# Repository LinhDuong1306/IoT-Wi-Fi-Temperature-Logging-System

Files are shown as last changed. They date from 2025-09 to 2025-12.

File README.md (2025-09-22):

# IoT Wi-Fi Temperature & Humidity Logging System with Alarm
This system records temperature data using a Atmega 328P microcontroller (MCU), Wi-Fi connectivity, and the ThingSpeak application programming interface (API). ThingSpeak is an open-source Internet of Things (IoT) platform that allows devices to send and retrieve data over the Internet.

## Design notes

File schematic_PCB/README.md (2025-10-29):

Thư mục này chứa các file về schematic và PCB

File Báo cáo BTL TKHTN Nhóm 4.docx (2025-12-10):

ĐẠI HỌC QUỐC GIA TP HỒ CHÍ MINH

TRƯỜNG ĐẠI HỌC BÁCH KHOA

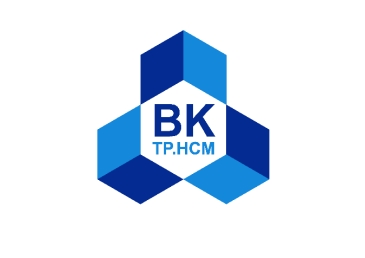
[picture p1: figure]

BÁO CÁO BÀI TẬP LỚN

ĐỀ TÀI

IoT-Wi-Fi Temperature & Humidity Logging System with Alarm

Môn: Thiết kế Hệ thống nhúng

GVHD: Ths BÙI QUỐC BẢO

Họ và tên | MSSV | Nhiệm vụ | Tỉ lệ
Dương Thị Khánh Linh | 2211841 | Thiết kế Hardwave | 100%
Nguyễn Hữu Vinh | 2213970 | Code | 100%

# I. Tổng quan

Trong bối cảnh các hệ thống tự động hóa và công nghệ Internet of Things (IoT) ngày càng phát triển, việc giám sát và đánh giá các thông số môi trường trở nên cần thiết đối với nhiều lĩnh vực khác nhau. Nhiệt độ và độ ẩm là hai yếu tố quan trọng ảnh hưởng trực tiếp đến chất lượng sản phẩm, điều kiện bảo quản, sự ổn định của thiết bị cũng như sức khỏe của con người. Vì vậy, một hệ thống giám sát nhiệt độ và độ ẩm hoạt động liên tục, chính xác và có khả năng cảnh báo kịp thời là yêu cầu cấp thiết trong nhiều ứng dụng thực tiễn.

Hệ thống IoT–Wi-Fi Temperature & Humidity Logging System with Alarm được xây dựng nhằm đáp ứng nhu cầu nói trên. Hệ thống cho phép đo lường và ghi nhận (logging) các giá trị nhiệt độ và độ ẩm theo thời gian thực, đồng thời truyền dữ liệu qua kết nối Wi-Fi lên nền tảng lưu trữ hoặc dashboard trực quan. Thông qua cơ chế cảnh báo tự động, hệ thống sẽ phát hiện và thông báo ngay lập tức khi thông số môi trường vượt ra khỏi giới hạn cho phép, giúp người vận hành kịp thời đưa ra biện pháp xử lý.

Hệ thống phù hợp cho:

- Kho lạnh, phòng thí nghiệm
- Nông nghiệp thông minh
- Nhà ở, văn phòng, phòng Server
- Nhà kính, chuồng trại chăn nuôi
- Quản lý chuỗi cung ứng thực phẩm

# II. Tổng quan hệ thống

## 1. Requirement

Hệ thống IoT-Wi-Fi Temperature & Humidity Logging System with Alarm được thiết kế nhằm mục đích giám sát và ghi lại dữ liệu nhiệt độ và độ ẩm trong môi trường một cách liên tục và chính xác. Hệ thống không chỉ cung cấp khả năng thu thập dữ liệu từ xa thông qua kết nối Wi-Fi mà còn tích hợp chức năng cảnh báo khi các thông số vượt ngưỡng cho phép, giúp người dùng kịp thời xử lý và duy trì điều kiện môi trường ổn định.

Yêu cầu của hệ thống bao gồm khả năng đo lường chính xác, truyền dữ liệu ổn định, cảnh báo tức thì và giao diện người dùng thân thiện để theo dõi và quản lý dữ liệu hiệu quả. Do đó nhóm đưa ra các yêu cầu hệ thống như sau.

  1.1. Functional Requirement

Number | Description | Note
R1.1 | Đọc được giá trị nhiệt độ & độ ẩm từ cảm biến
R1.2 | Hiển thị dữ liệu đo được lên LCD (Temp xx.x °C, Humi xx.x %RH).
R1.3 | Kết nối Wi-Fi
R1.4 | Gửi dữ liệu (Temp, Humi) lên phần mềm và ứng dụng
R1.5 | Chu kỳ gửi dữ liệu < 30 giây.
R1.6 | Lưu dữ liệu khi mất Wi-Fi.
R1.7 | Tự động đồng bộ dữ liệu khi Wi-Fi phục hồi.
R1.8 | Người dùng có thể xem dữ liệu theo thời gian thực trên trang web hoặc ứng dụng phát triển.
R1.9 | Kích hoạt báo động (buzzer) khi nhiệt độ hoặc độ ẩm vượt ngưỡng.

  1.2. Non-functioanl Requirement

Number | Description | Note
R2.1 | Độ chính xác: Nhiệt độ ±0.5 °C, Độ ẩm ±2 %RH
R2.2 | Ứng dụng hiển thị biểu đồ line chart (Temp & Humi)
R2.3 | Độ trễ từ lúc đo đến khi gửi dữ liệu ≤ 2 giây.
R2.4 | Hoạt động trong môi trường -30 °C đến 80 °C.
R2.5 | Nguồn DC 12V-1A, ổn áp xuống 5V/3.3V.
R2.6 | Sử dụng giao thức HTTP/MQTT chuẩn do phần mềm hiển thị hỗ trợ.
R2.7 | Chi phí linh kiện < 500.000 VND.
R2.8 | Báo động phát trong ≤2 giây kể từ khi vượt ngưỡng.

## 1. Hoạt động hệ thống

Nguyên lý hoạt động của hệ thống gồm ba giai đoạn chính diễn ra tuần hoàn là khởi tạo, xử lý dữ liệu tại chỗ và truyền thông dữ liệu từ xa.

Đầu tiên, ở giai đoạn Khởi tạo, ngay khi được cấp nguồn, khối xử lý trung tâm thực hiện việc cấu hình các chân tín hiệu và kết nối với cảm biến. Đồng thời, module Wi-Fi tích hợp sẽ tiến hành xác thực và kết nối vào mạng Internet cục bộ. Đèn báo trạng thái sẽ phản hồi để xác nhận kết nối mạng thành công, đưa hệ thống vào trạng thái sẵn sàng hoạt động.

Tiếp theo là giai đoạn Thu nhập và Xử lý tại chỗ. Vi điều khiển định kỳ đọc dữ liệu từ cảm biến nhiệt độ và độ ẩm và hiển thị lên LCD. Các giá trị này được so sánh trực tiếp với ngưỡng cảnh báo được thiết lập trong phần mềm (ví dụ: nhiệt độ T > 35ᵒC). Nếu kết quả so sánh cho thấy thông số nằm trong giới hạn an toàn, hệ thống duy trì trạng thái giám sát bình thường. Tuy nhiên, nếu phát hiện thông số vượt ngưỡng, vi điều khiển sẽ kích hoạt khối cảnh báo: còi buzzer sẽ phát âm thanh báo động để cảnh báo người dùng tại hiện trường xử lý kịp thời. Có một nút nhấn cho phép bật tắt cảnh báo, ban đầu là hệ thống cho cho phép cảnh báo hoạt động đồng thời led báo hiệu sáng, sau khi cảnh báo đã bật, khi nhấn nút cảnh báo sẽ tắt đồng thời led báo hiệu cũng tắt.

Cuối cùng là giai đoạn Ghi dữ liệu và Giám sát từ xa (IoT Logging). Bất kể trạng thái là bình thường hay cảnh báo, dữ liệu nhiệt độ và độ ẩm đều được vi điều khiển đóng gói và gửi lên máy chủ đám mây (Cloud Server) thông qua giao thức mạng (như HTTP hoặc MQTT). Nền tảng Cloud (như ThingSpeak, Blynk) sẽ nhận gói tin, lưu trữ dữ liệu theo thời gian thực và cập nhật biểu đồ trên giao diện người dùng. Điều này cho phép người quản lý không chỉ theo dõi tình trạng hiện tại mà còn có thể xem lại lịch sử biến thiên của môi trường theo thời gian. Sau khi hoàn tất gửi dữ liệu, hệ thống chuyển sang chế độ chờ trong một khoảng thời gian định trước khi bắt đầu chu kỳ đo mới.

## 2. Block digram

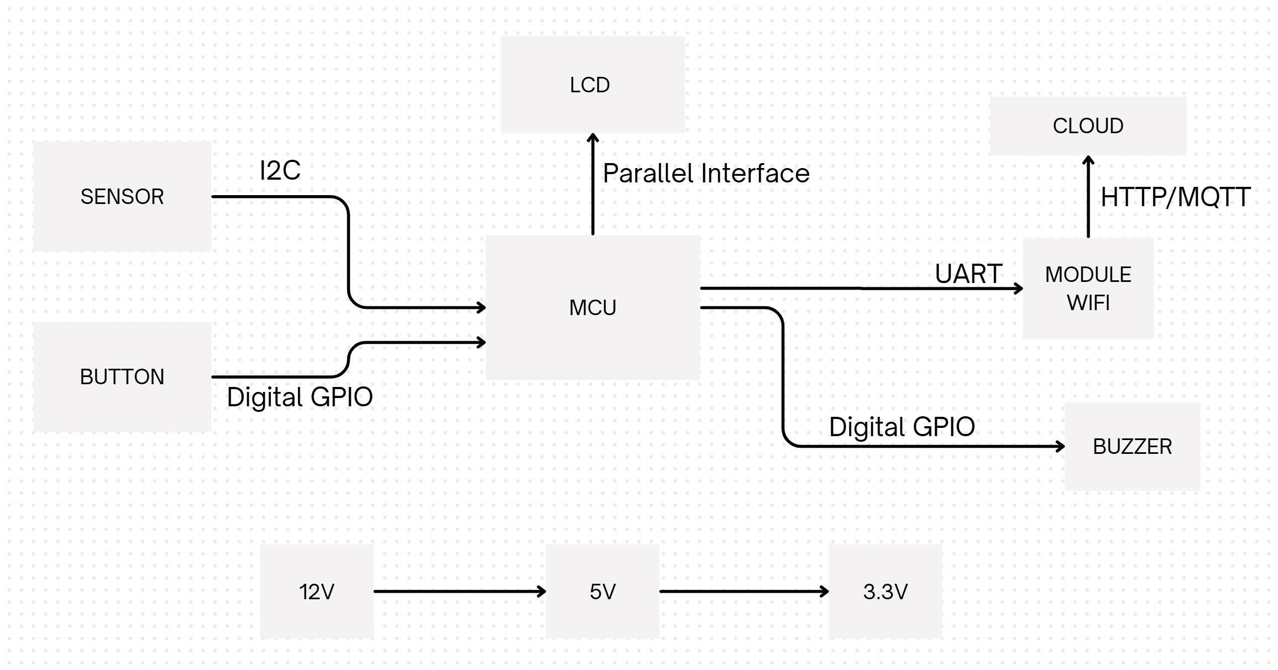
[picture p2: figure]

# III. Thiết kế phần cứng

## 1. Các thành phần, khối

Hệ thống gồm các khối sau:

  1.1. Khối cảm biến

Yêu cầu độ chính xác Nhiệt độ ±0.5 °C, Độ ẩm ±2 %RH, từ đó lựa chọn Sensor nhiệt độ, độ ẩm AHT20 cho thiết kế, IC có nguồn cấp là 5V. Giao tiếp bằng giao thức I2C. Tụ lọc nguồn của IC có công thức tính như sau:

C≥(I_(trsnsient) ×∆t)/(∆V_(ripple))

Chọn tụ có giá trị 1uF

  1.2. Khối module wifi

Yêu cầu có thể gửi dữ liệu lên Internet, có thể kết nối wifi, khoảng cách giữa các các lần gửi ≤ 30s. Có thể truyền dữ liệu bằng giao thức MQTT hoặc HTTP. Từ đó lựa chọn ESP8266 ESP – 01 để thực hiện chức năng này. Giao tiếp bằng giao thức UART.

ESP – 01 có điện áp cấp là 3.3V tương tự cho các IC khác ta cũng có tụ bypass nguồn cho ESP – 01 có giá trị 1uF. Và có nhút nhấn button reset cho module này.

  1.3. Khối hiển thị, cảnh báo

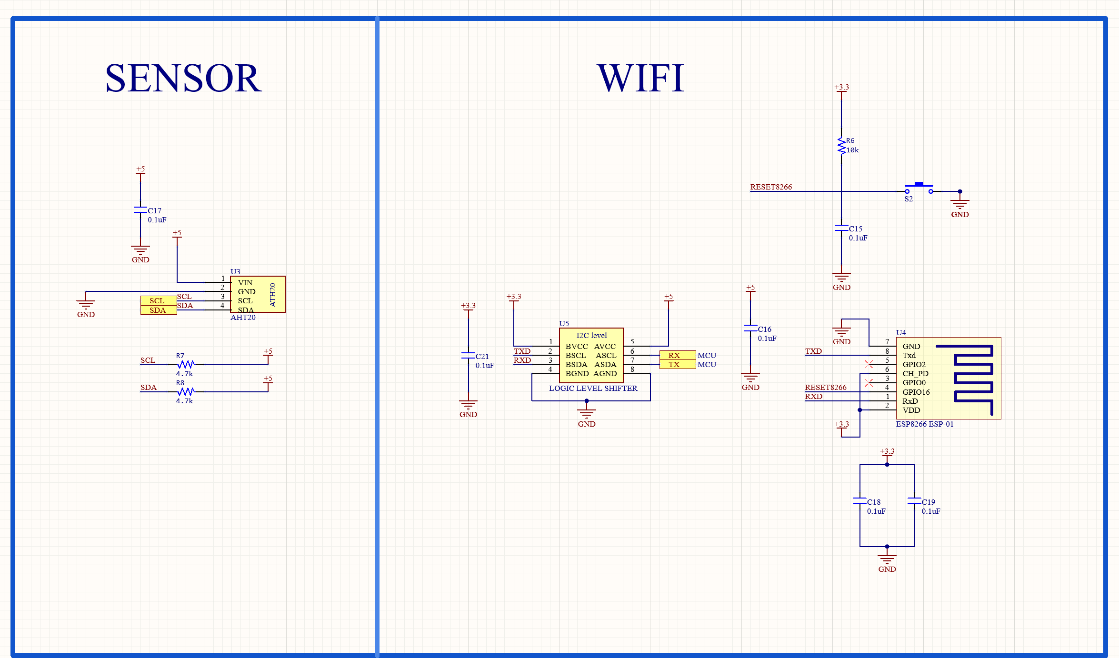
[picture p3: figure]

Hiển thị thông tin cho người dùng: Nhiệt độ, Độ ẩm, Thời gian cho lần gửi dữ liệu tiếp theo. Có Nhận dữ liệu từ MCU và hiển thị text ra màn hình qua giao tiếp. Sử dụng LCD1602 cho mạch, hiển thị.

Còi báo để cảnh báo khi vượt ngưỡng nhiệt độ hoặc độ ẩm. Nhận tín hiệu digital từ MCU, phát âm thanh qua buzzer và phải dùng transistor NPN để khuếch đại dòng, hay để lái Buzzer. Lựa chọn còi passive 5V, Transitor NPN để thực hiện mạch còi.

Thiết kế một nút nhấn button_alarm cho hệ thống với hệ thống.

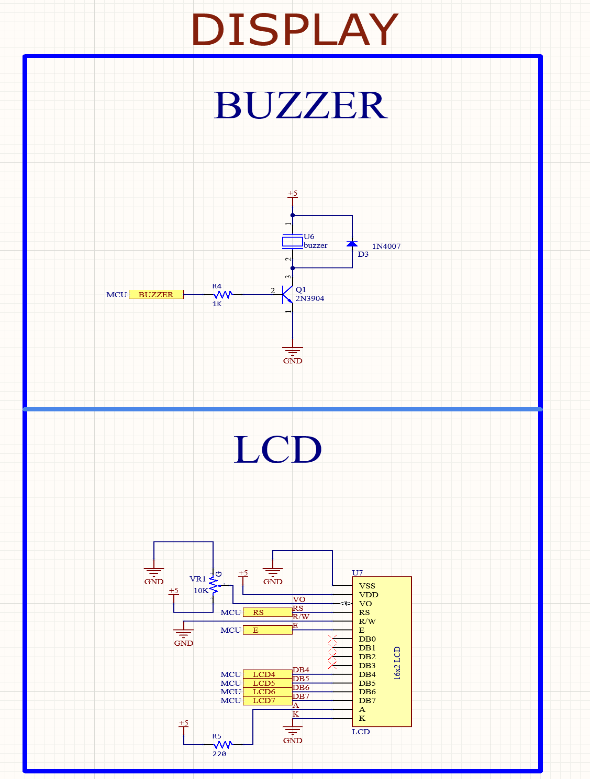
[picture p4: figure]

  1.4. Khối MCU

Hệ thống sử dụng cảm biến AHT20, module WiFi ESP8266, LCD 1602, nút nhấn và còi báo, nên cần một bộ điều khiển có khả năng hỗ trợ đồng thời nhiều chuẩn giao tiếp như I2C để đọc dữ liệu cảm biến, UART để truyền dữ liệu với module WiFi, và các chân GPIO để điều khiển còi, đọc tín hiệu từ nút nhấn cũng như giao tiếp song song với LCD. MCU có đủ số chân I/O để kết nối toàn bộ các thiết bị này mà không cần thêm IC mở rộng. MCU cần có 6 chân điều khiển LCD, 2 chân I2C, 2 chân UART, 2 chân GPIO cho button và buzzer và 4 chân cho mạch nạp code. Tổng 16 I/O, do đó lựa chọn ATmega 328P có 28 chân, trong đó có 20 chân I/O, thư viện phong phú giá thành rẻ làm là vi điều khiển cho toàn hệ thống.

Thiết kế một button_reset cho MCU, tương tự ta chọn các giá trị tụ bypass nguồn để lọc nhiễu đầu vào cho MCU sử dụng công thức trên ta dùng 2 tụ có giá trị 1uF.

Chọn thạch anh ngoài 16MHZ để tạo xung cho mạch. Các tụ đầu vào của thạch anh có giá trị được tính theo công thức:

C_L =(C_1 C_2)/(C_1 +C_2)+C_(stray)

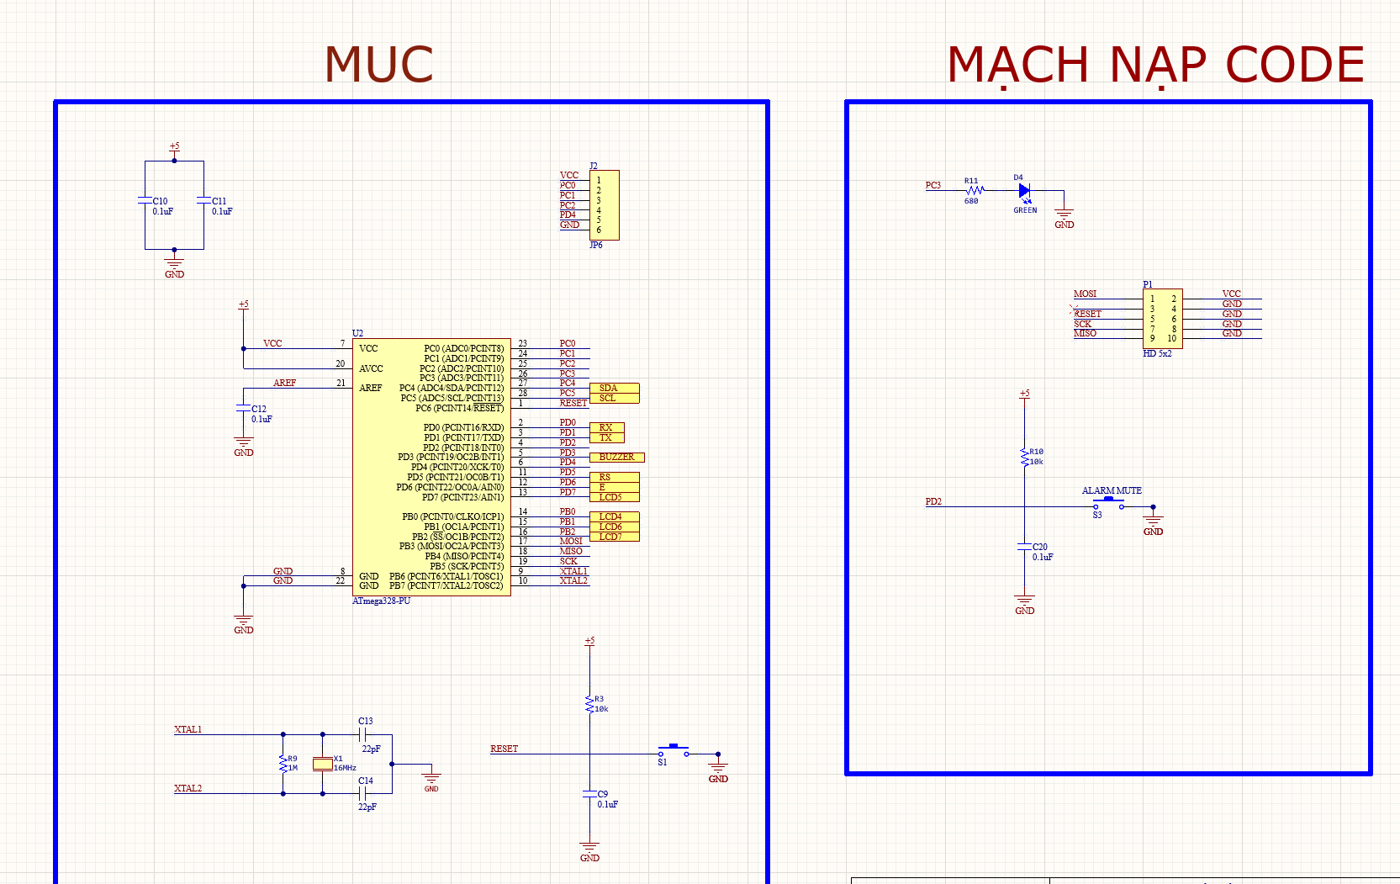
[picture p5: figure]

Chọn C_1 =C_2 , suy ra C có giá trị là 22pF.

  1.5. Khối nguồn

Lựa chọn nguồn Adapter 12V/1A cấp nguồn vào sau đó chuyển đổi xuống 5V để cấp cho MCU, buzzer, LCD và cảm biến. Do đó cần một IC chuyển nguồn, nhóm lựa chọn IC LM7805 để thực hiện tác vụ này. Sử dụng công thức:

C≥(I_(trsnsient) ×∆t)/(∆V_(ripple))

V_(rating) ≥2V_(use)

Chọn tụ 47uF/35V làm chức năng lọc nhiễu và ripple từ adapter đồng thời ổn định đầu vào trước khi vào ổn áp LM7805. Gắn tản nhiệt cho LM7805 ta có:

P_d =(V_(in) -V_(out) )I_(out)

I_(max) =(T_(jmax) -T_a)/((V_(in) -V_(out) )θ_(ja))=700mA

Thêm 1 tụ 22uF/16V đầu vào để lọc ripple từ nguồn cung cấp.

Z_c =1/(2πfC)

Từ đó chọn một tụ ceramic 0.1uF cho HF ở ngõ ra để tần số nhiễu nhỏ. Và một tụ electrolytic 10uF/16V song song với tụ ceramic để ổn định điện áp ngõ ra. Mắc một R và LED để kiểm tra bộ ổn áp hoạt động. Chọn R = 1k, dòng chạy qua nhỏ đủ làm LED sáng và không gây hao hụt gây nóng cho 7805.

I=(5-2)/R=3mA

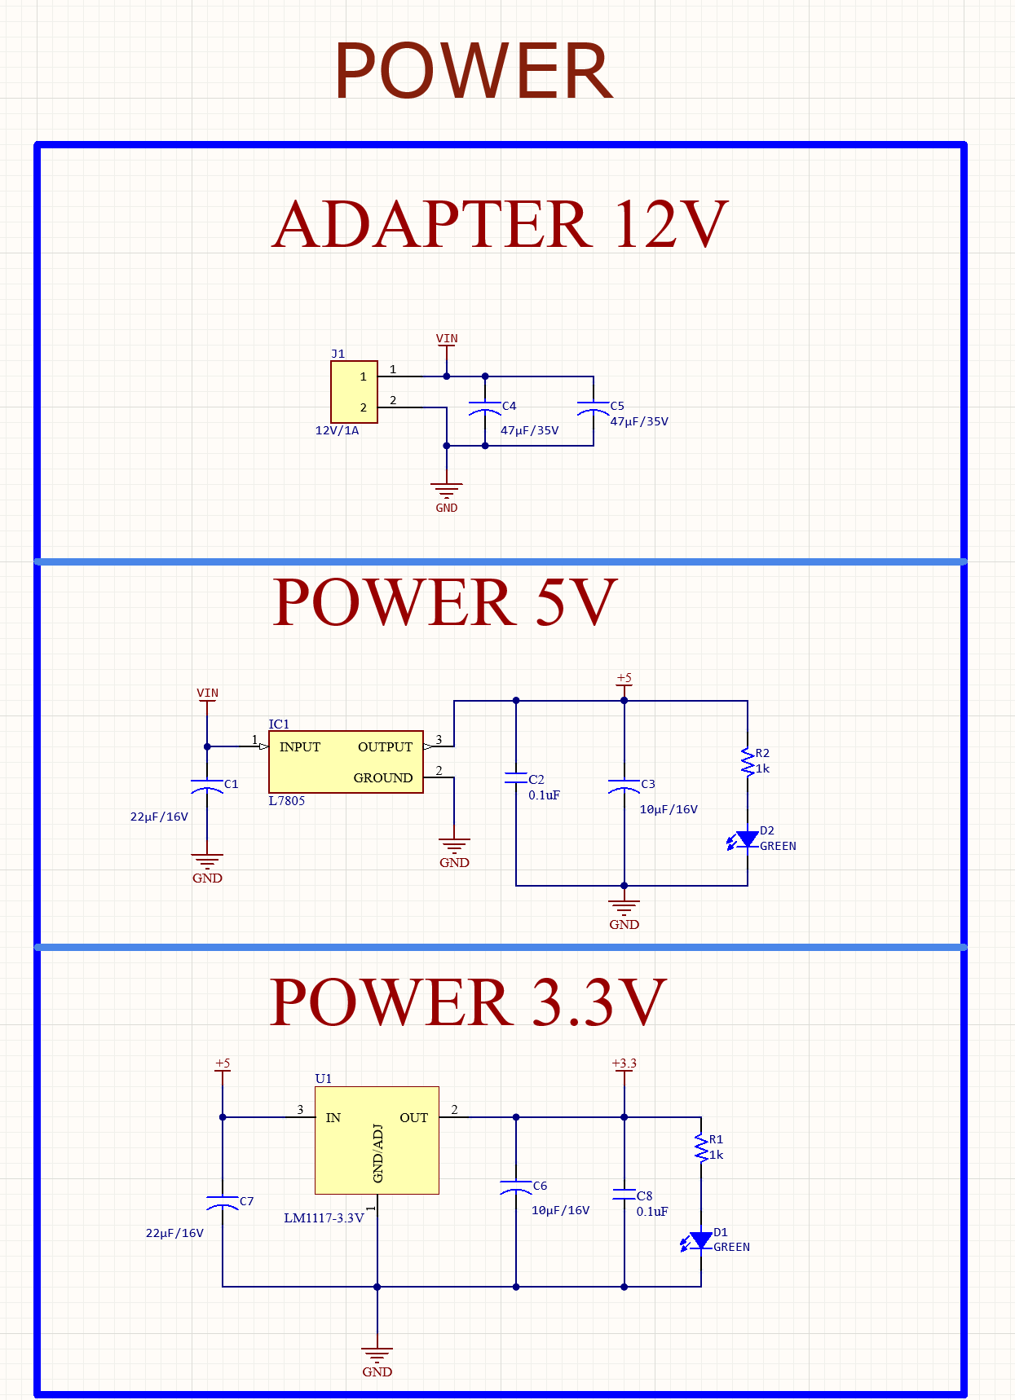
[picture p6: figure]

Bộ chuyển đổi từ 5V về 3.3V để cấp nguồn cho ESP8266 hay ESP-01 tương tự cấu trúc trên.

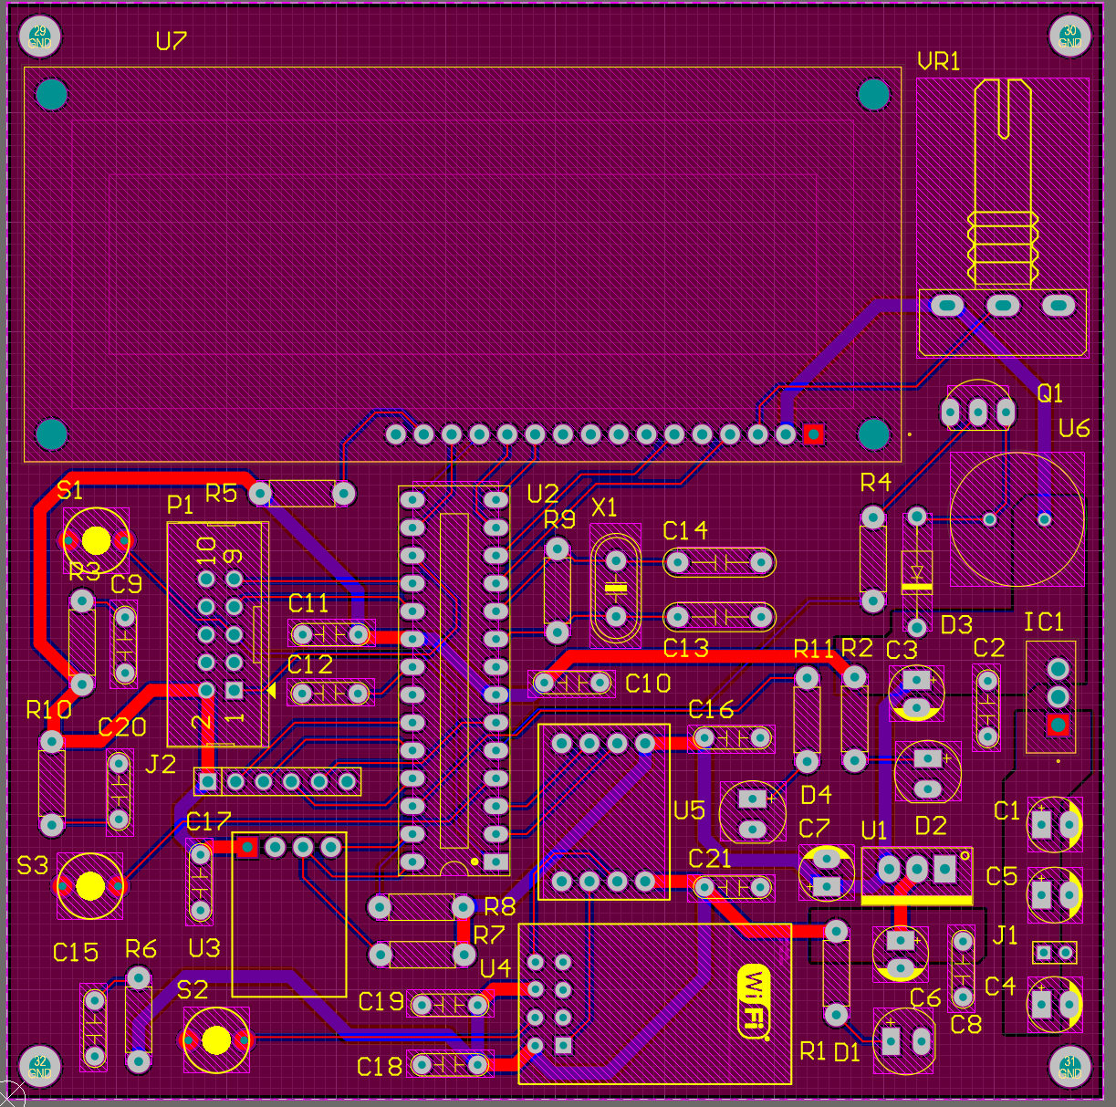
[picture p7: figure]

## 1. Layout PCB

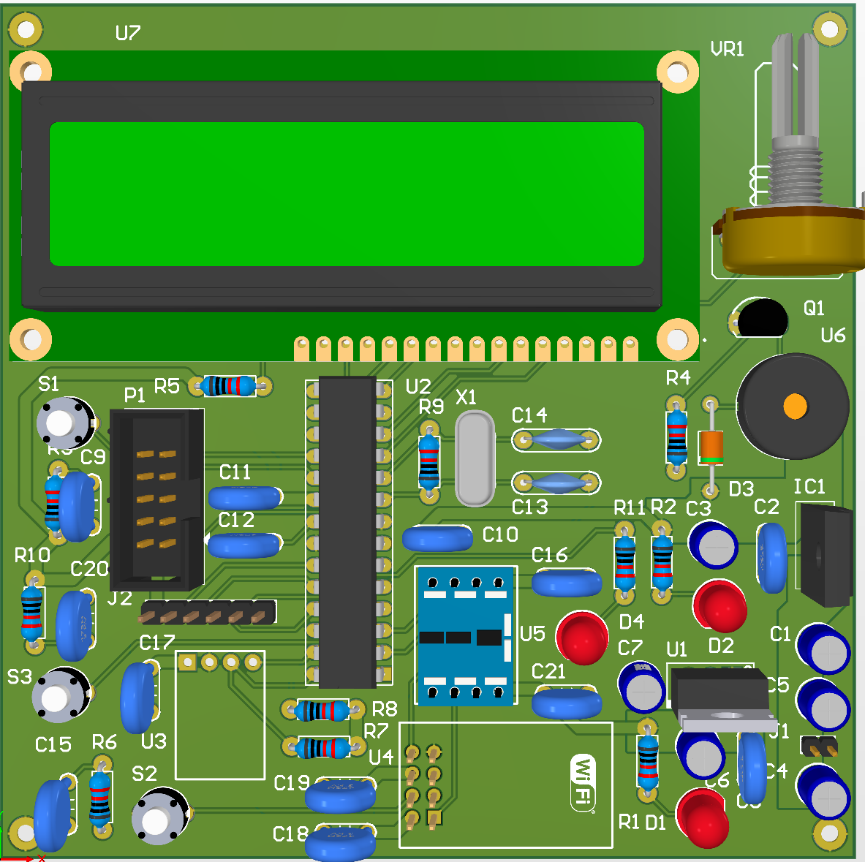
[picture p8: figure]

Mô hình 3D

# IV. Thiết kế phần mềm

## 1. Flow chart button

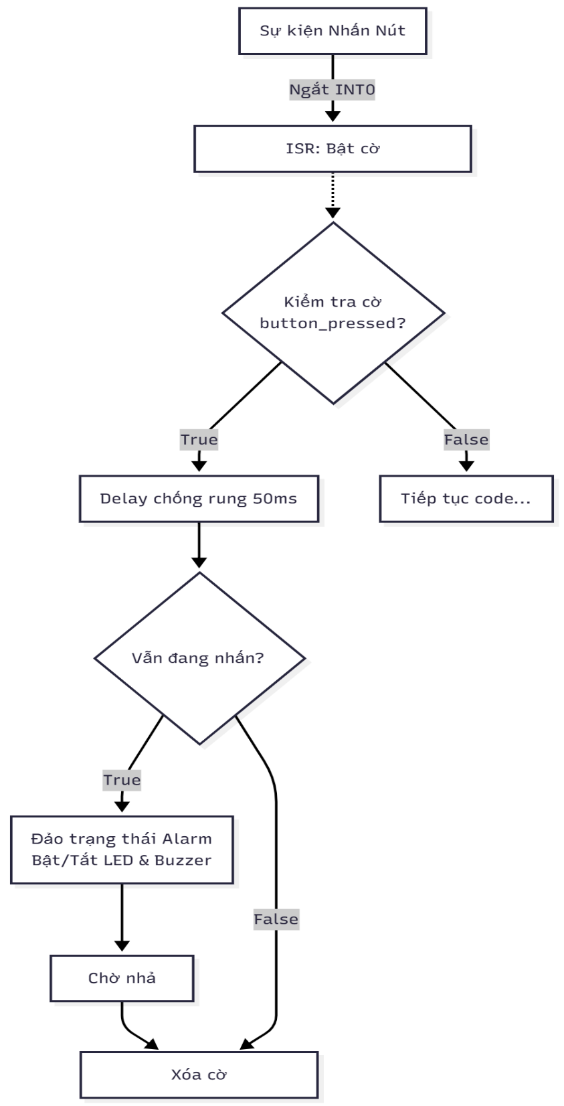
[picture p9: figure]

## 2. Flow chart hệ thống

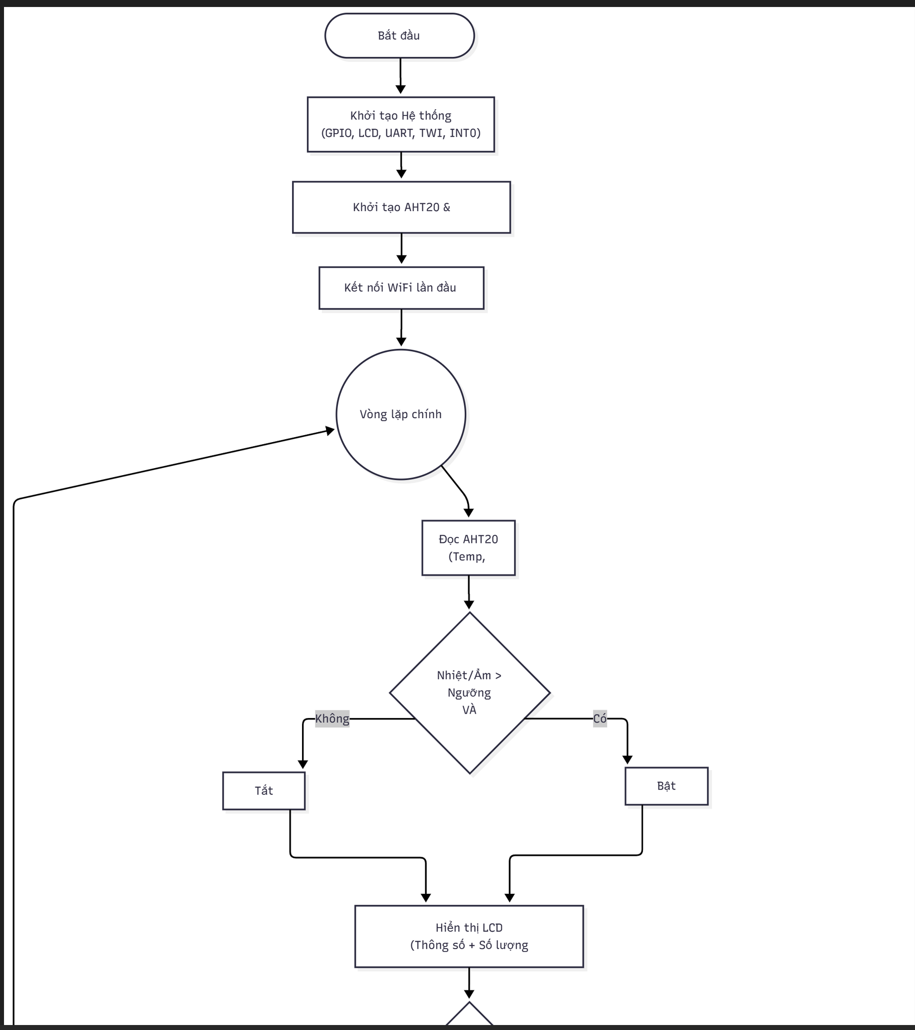
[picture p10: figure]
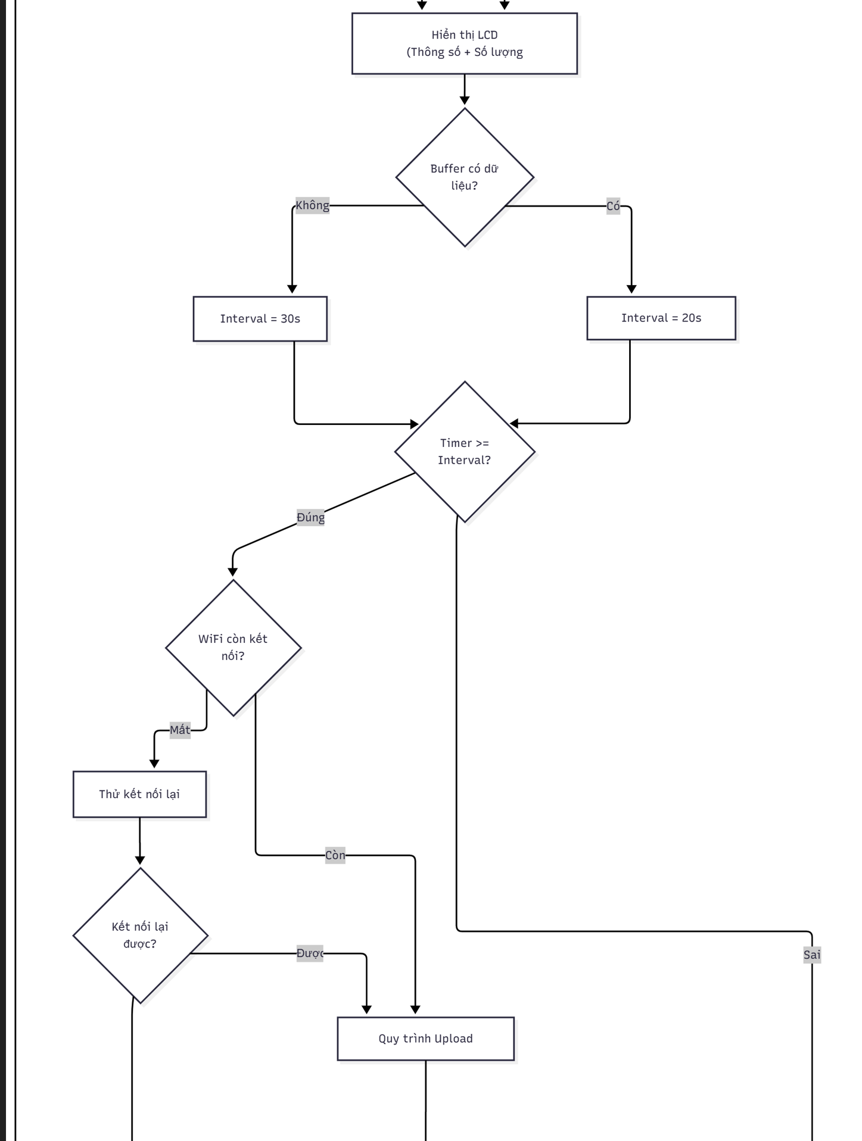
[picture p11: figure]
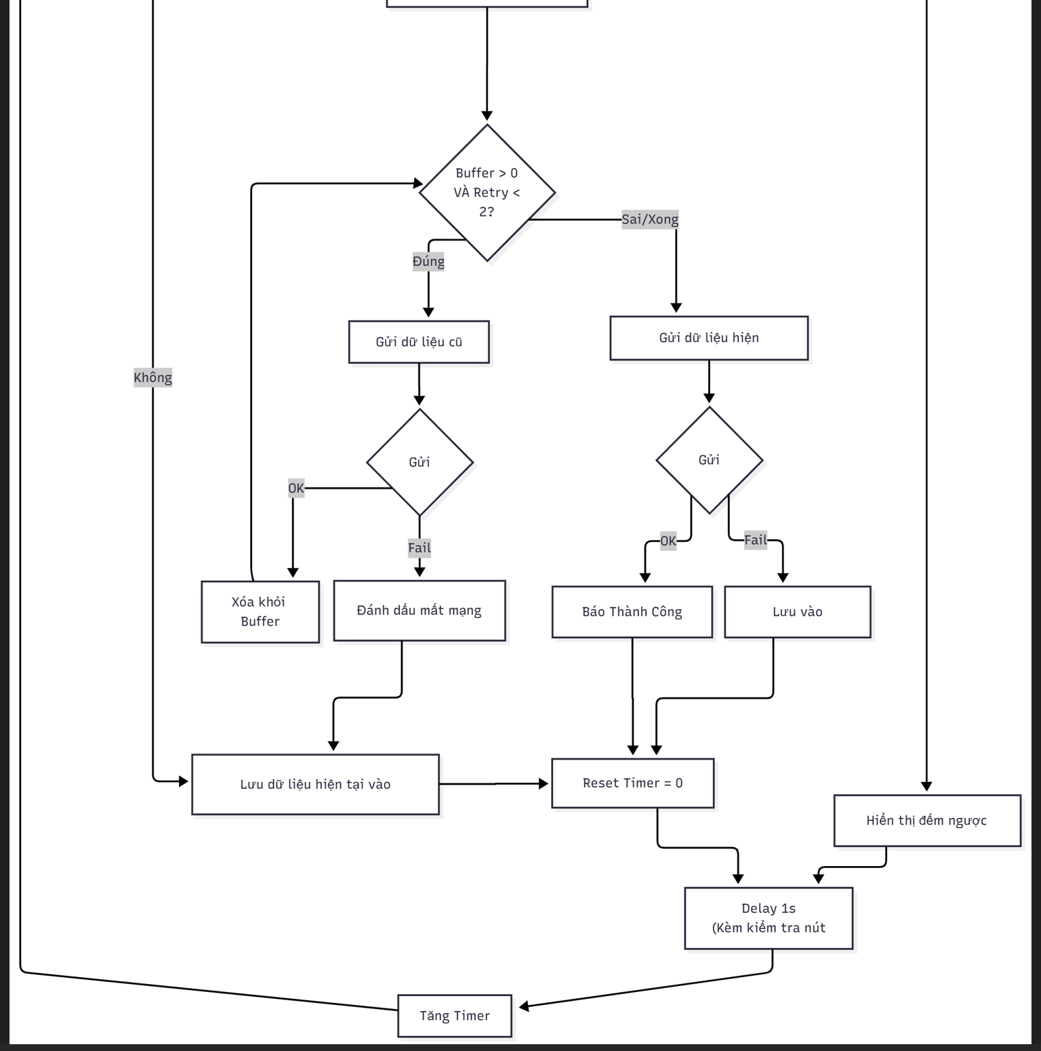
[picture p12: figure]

# V. Kết quả

Hệ thống đã được thiết kế và lắp ráp hoàn chỉnh trên [bo mạch in PCB / test board], đảm bảo tính thẩm mỹ và các yêu cầu kỹ thuật đề ra:

- Khối xử lý trung tâm (ATmega328P): Hoạt động ổn định với thạch anh ngoại 16MHz, đảm bảo tốc độ xử lý và đồng bộ truyền thông UART chính xác.
- Khối cảm biến (AHT20): Giao tiếp I2C hoạt động tốt nhờ các điện trở kéo lên (Pull-up) và tụ lọc nhiễu 0.1µF đặt sát chân cảm biến.
- Khối WiFi (ESP-01): Module hoạt động ổn định, không bị hiện tượng khởi động lại (reset) đột ngột nhờ hệ thống tụ lọc nguồn (10µF + 0.1µF) và mạch hạ áp 3.3V riêng biệt. Giao tiếp UART giữa MCU (5V) và ESP (3.3V) hoạt động tốt nhờ cầu phân áp.

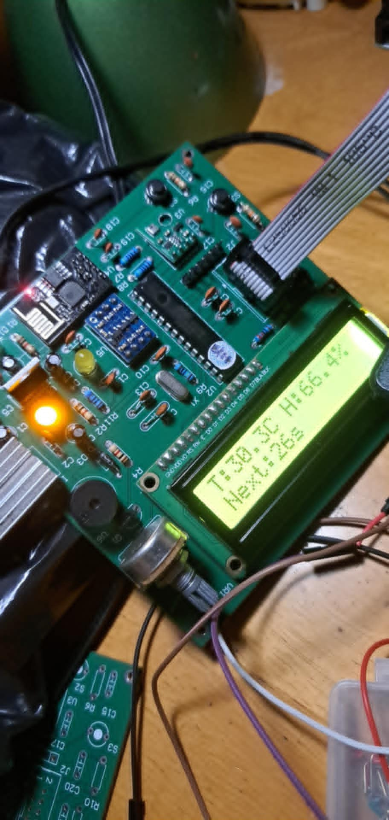
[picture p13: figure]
Mở ảnh

Khi hệ thống khởi động, dữ liệu được thu thập và hiển thị qua cổng Serial để phục vụ quá trình kiểm tra (Debug):

- Hệ thống kết nối thành công với mạng WiFi.
- Cảm biến AHT20 trả về giá trị nhiệt độ và độ ẩm.
- Dữ liệu hiển thị rõ ràng, không bị lỗi font hoặc mất ký tự.

Hệ thống thực hiện thành công chức năng gửi dữ liệu lên ThingSpeak

- Độ trễ: Dữ liệu được cập nhật lên server gần như tức thời sau khi đo (độ trễ khoảng 1-2 giây phụ thuộc mạng).
- Tính toàn vẹn: Các gói tin gửi đi đầy đủ, không bị ngắt quãng trong quá trình thử nghiệm kéo dài 1 tiếng.
- Biểu đồ: Server vẽ được biểu đồ biến thiên nhiệt độ và độ ẩm theo thời gian thực.

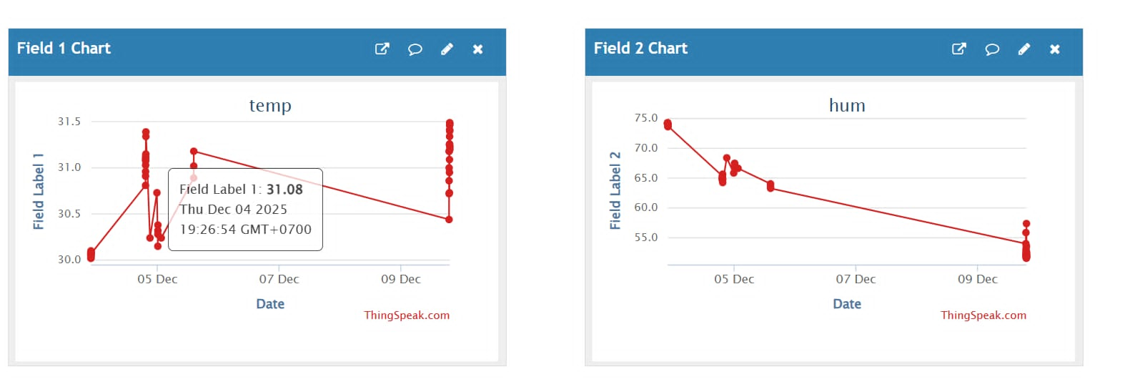
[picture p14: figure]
Mở ảnh

# VI. Kết luận

## 1. Kết luận

Kết quả thực nghiệm cho thấy hệ thống giám sát và lưu trữ dữ liệu môi trường hoạt động ổn định và đáp ứng tốt các yêu cầu về IoT. Module Wi-Fi duy trì kết nối liên tục, đảm bảo việc truyền tải dữ liệu từ cảm biến AHT20 lên máy chủ đám mây ThingSpeak diễn ra xuyên suốt với độ trễ thấp. Dữ liệu nhiệt độ và độ ẩm được cập nhật theo thời gian thực (Real-time) và hiển thị trực quan trên giao diện web/app, giúp người dùng dễ dàng theo dõi biến động môi trường từ xa mà không xảy ra hiện tượng mất mát dữ liệu.

## 2. Hướng phát triển

Qua quá trình thiết kế và thực nghiệm, hệ thống IoT giám sát nhiệt độ và độ ẩm đã hoạt động ổn định, đảm bảo đầy đủ các yêu cầu kỹ thuật đề ra. Cảm biến môi trường thu thập dữ liệu với độ chính xác cao, trong khi module Wi-Fi duy trì kết nối ổn định giúp dữ liệu được truyền lên nền tảng ThingSpeak liên tục theo thời gian thực, không xảy ra tình trạng mất gói tin. Kết quả này cho thấy hệ thống đáp ứng tốt chức năng giám sát và theo dõi các thông số môi trường một cách tin cậy. Tuy nhiên, để nâng cao tính ứng dụng thực tế và phát triển hệ thống theo hướng tự động hóa thông minh, đề tài sẽ tập trung mở rộng hai chức năng quan trọng trong giai đoạn tiếp theo. Thứ nhất, tích hợp cơ chế cảnh báo tức thời qua tin nhắn hoặc ứng dụng di động khi các chỉ số môi trường vượt ngưỡng cho phép nhằm giúp người dùng kịp thời xử lý sự cố. Thứ hai, bổ sung khối chấp hành sử dụng relay để điều khiển các thiết bị ngoại vi như quạt hoặc máy phun sương, giúp hệ thống tự động điều chỉnh và duy trì trạng thái môi trường ổn định. Ngoài ra, đề tài cũng hướng đến việc tối ưu hóa năng lượng bằng cách áp dụng chế độ Deep Sleep cho vi điều khiển và nghiên cứu khả năng sử dụng nguồn năng lượng mặt trời, từ đó giúp hệ thống có thể hoạt động lâu dài và độc lập tại các khu vực không có điện lưới như nhà kính hoặc trang trại xa trung tâm. Với những định hướng trên, hệ thống hứa hẹn trở thành một giải pháp IoT toàn diện, thông minh và có tính ứng dụng cao trong thực tế.

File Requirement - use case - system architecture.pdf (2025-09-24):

IoT-Wi-Fi Temperature & Humidity Logging System with Alarm | Nhóm 4
1. Mục tiêu (Mission Objective)
Hệ thống đo nhiệt độ & độ ẩm từ cảm biến AHT20, hiển thị tại chỗ trên LCD, truyền dữ liệu qua Wi-Fi (ESP8266) lên nền tảng IoT (ThingSpeak). Ngoài ra, hệ thống có cảnh báo tại chỗ (buzzer) khi giá trị vượt ngưỡng cấu hình.
2. Functional Requirement
Number | Description | Note
R1.1 | Đọc được giá trị nhiệt độ & độ ẩm từ cảm biến AHT20 qua I²C.
R1.2 | Hiển thị dữ liệu đo được lên LCD (Temp xx.x °C, Humi xx.x %RH). | Cập nhật mỗi chu kỳ
R1.3 | Kết nối Wi-Fi bằng ESP8266. | UART
R1.4 | Gửi dữ liệu (Temp, Humi) lên ThingSpeak bằng API Key. | Field1 = Temp, Field2 = Humi
R1.5 | Chu kỳ gửi dữ liệu ≥ 15 giây. | Theo giới hạn ThingSpeak
R1.6 | Lưu dữ liệu khi mất Wi-Fi. | EEPROM/Flash
R1.7 | Tự động đồng bộ dữ liệu khi Wi-Fi phục hồi. | FIFO
R1.8 | Người dùng có thể xem dữ liệu theo thời gian thực trên ThingSpeak. | Web/App
R1.9 | Kích hoạt báo động (buzzer) khi nhiệt độ hoặc độ ẩm vượt ngưỡng. | Ngưỡng cài đặt trước
2.1. Đọc giá trị từ AHT20
- Giao tiếp: I²C.
- Chu kỳ đọc: 15 giây/lần (cấu hình được).
- Dải đo:
- Nhiệt độ: -40 ~ +85 °C, sai số ±0.3 °C.
- Độ ẩm: 0 ~ 100 %RH, sai số ±2 %RH.
- Nếu cảm biến trả về lỗi (CRC hoặc không ACK) → hệ thống báo lỗi.
2.2. Hiển thị LCD
- Người dùng có thể quan sát trực tiếp nhiệt độ tại thiết bị.
- LCD 16x2 hiển thị định dạng
- Dòng 1: Temp: xx.x °C.
- Dòng 2: Humi yy.y%
- Nếu lỗi cảm biến hiển thị “Sensor Error”
- Cập nhật theo chu kỳ đọc cảm biến.
- Nếu mất tín hiệu cảm biến → hiển thị lỗi.
- Ký tự hiển thị rõ ràng, không vượt quá độ trễ 2 giây sau khi đo.
2.3. Wi-Fi (ESP8266)
- Hệ thống phải truyền dữ liệu qua mạng Wi-Fi để kết nối Internet.
- ESP8266 giao tiếp với Atmega 328 qua UART (AT Command hoặc firmware custom).
- Hỗ trợ chuẩn Wi-Fi 802.11 b/g/n, 2.4 GHz.

- Nếu Wi-Fi mất → hệ thống phải thử kết nối lại định kỳ.
- Cấu hình Wi-Fi (SSID, Password) lưu trong bộ nhớ Atmega 328 hoặc ESP8266
2.4. Gửi dữ liệu ThingSpeak
- Dữ liệu được truyền đến nền tảng IoT để giám sát từ xa.
- Dữ liệu gửi bằng HTTP POST hoặc MQTT (ThingSpeak hỗ trợ).
- Kèm API Key để xác thực người dùng.
- Mỗi bản tin gồm: thời gian (timestamp), nhiệt độ, độ ẩm.
- Tuân thủ giới hạn ThingSpeak (tối thiểu 15 giây giữa 2 lần gửi).
2.5. Chu kỳ gửi dữ liệu
- Đảm bảo dữ liệu cập nhật kịp thời nhưng không vượt giới hạn của server.
- Atmega 328 có bộ định thời (Timer) để điều khiển chu kỳ gửi.
- Tần suất mặc định: 15 giây, nhưng có thể cấu hình ≥ 15 giây.
- Nếu gửi lỗi → thử lại sau 15 giây tiếp theo.
- Không vi phạm policy ThingSpeak (không gửi nhanh hơn).
2.6. Lưu dữ liệu khi mất Wi-Fi
- Không mất dữ liệu trong thời gian Wi-Fi gián đoạn.
- Dữ liệu nhiệt độ lưu tạm vào EEPROM/Flash.
- Ghi kèm timestamp (từ NTP hoặc RTC nội bộ).
- Bộ nhớ tối thiểu phải lưu được ~100 bản ghi khi mất mạng dài hạn.
- Bộ nhớ giới hạn, cần cơ chế ghi vòng tròn (FIFO).
2.7. Đồng bộ khi Wi-Fi khôi phục
- Đảm bảo dữ liệu liên tục, không mất gói khi giám sát từ xa.
- Khi Wi-Fi trở lại → hệ thống lần lượt gửi các bản ghi lưu trong EEPROM.
- Thứ tự đồng bộ: FIFO (theo thời gian đo).
- Khi bộ nhớ đầy → dữ liệu cũ nhất sẽ bị ghi đè.
- Không làm gián đoạn việc gửi dữ liệu hiện tại.
2.8. Xem dữ liệu trên ThingSpeak
- Người dùng theo dõi dữ liệu qua giao diện IoT.
- ThingSpeak hiển thị biểu đồ line chart theo thời gian.
- Dữ liệu cập nhật đúng chu kỳ gửi.
- Người dùng truy cập từ trình duyệt web hoặc app di động.
- Yêu cầu Internet và API Key hợp lệ để xem kênh dữ liệu.
2.9. Báo động
- Có buzzer cảnh báo khi vượt ngưỡng:
- Temp > Tmax (ví dụ: 40 °C)
- Temp < Tmin (ví dụ: 0 °C)
- Humi > Hmax (ví dụ: 80 %RH)
- Humi < Hmin (ví dụ: 20 %RH)
- Ngưỡng có thể cấu hình trong firmware.-

- Báo động dừng khi giá trị quay về trong ngưỡng an toàn hoặc có nút Reset.
3. Non-functioanl Requirement
Number | Description | Note
R2.1 | Độ chính xác: Nhiệt độ ±0.3 °C, Độ ẩm ±2 %RH
R2.2 | ThingSpeak hiển thị biểu đồ line chart (Temp & Humi)
R2.3 | Độ trễ từ lúc đo đến khi gửi dữ liệu ≤ 2 giây.
R2.4 | Hoạt động trong môi trường -30 °C đến 80 °C.
R2.5 | Nguồn DC 12V-1A, ổn áp xuống 5V/3.3V.
R2.6 | Sử dụng giao thức HTTP/MQTT chuẩn do ThingSpeak hỗ trợ.
R2.7 | Chi phí linh kiện < 500.000 VND.
R2.8 | Báo động phát trong ≤1 giây kể từ khi vượt ngưỡng.

3.1.Độ chính xác đo nhiệt độ sai số không vượt quá ±1 °C

- Đảm bảo dữ liệu đo có độ tin cậy cho giám sát và phân tích.
- Cảm biến AHT20 có sai số:
- Nhiệt độ: ±0.3 °C (trong dải -40 °C → 85 °C).
- Độ ẩm: ±2 %RH (trong dải 20 % → 80 %RH).
- Cần hiệu chỉnh (calibration) ban đầu để giảm sai số hệ thống.
- Vì AHT20 xuất dữ liệu digital (I²C) nên không phụ thuộc vào ADC, giúp tránh nhiễu và sai số do nguồn tham chiếu.

3.2.Giao diện ThingSpeak phải hiển thị biểu đồ dữ liệu kiểu line chart
- Người dùng dễ dàng theo dõi sự biến đổi nhiệt độ theo thời gian.
- ThingSpeak kênh dữ liệu phải bật chế độ “Line Chart”.
- Biểu đồ line chart:
- Field1 = Nhiệt độ (°C).
- Field2 = Độ ẩm (%RH).
- Trục X: thời gian (timestamp), trục Y: giá trị cảm biến.
- Biểu đồ có thể hiển thị theo ngày, giờ hoặc thời gian thực.
- Phụ thuộc vào tính năng visualization của ThingSpeak.

3.3.Từ lúc đo đến lúc gửi dữ liệu không quá 2 giây
- Đảm bảo độ trễ thấp, dữ liệu cập nhật gần với thời gian thực.
- AHT20 có thời gian đo ~80–100 ms.
- Xử lý dữ liệu & hiển thị LCD < 500 ms.
- Gửi dữ liệu ThingSpeak qua Wi-Fi < 1.5 giây (nếu mạng ổn định).
- Tổng độ trễ < 2 giây.

3.4.Hệ thống phải hoạt động trong dải nhiệt độ môi trường -30 °C đến 80 °C

- Cho phép thiết bị hoạt động ổn định trong nhiều điều kiện môi trường.
- Linh kiện chọn loại chịu nhiệt độ công nghiệp (-40 °C → +125 °C).
- Vỏ bảo vệ chống ẩm, bụi.
- Nguồn adapter và LCD có thể hạn chế dải hoạt động (0–70 °C), cần chọn loại phù hợp.

3.5.Sử dụng nguồn một chiều 12V-1A
- Cung cấp đủ năng lượng cho hệ thống (ATmega 328 + ESP8266 + LCD).
- Dùng adapter 12V-1A, có IC ổn áp xuống 5V và 3.3V.
- Công suất tối thiểu 12W, đủ cho các module hoạt động đồng thời.
- Cần mạch bảo vệ chống ngắn mạch, quá dòng.

3.6.Sử dụng giao thức HTTP/MQTT chuẩn do ThingSpeak hỗ trợ
- Đảm bảo khả năng tích hợp với nền tảng IoT phổ biến.
- Hệ thống hỗ trợ HTTP POST hoặc MQTT publish.
- Có khả năng thêm Header chứa API Key để xác thực.
- Giới hạn tốc độ gửi dữ liệu của ThingSpeak (≥15 giây/lần).

3.7.Chi phí linh kiện ít hơn 500.000 VND
- Đảm bảo hệ thống rẻ, dễ triển khai cho nghiên cứu/DIY.
- Tmega328, AHT20, LCD, ESP8266, buzzer/LED, EEPROM/Flash, nguồn, PCB.
- Tổng chi phí < 500k VND (chưa tính công lắp ráp).
3.8. Thời gian đáp ứng báo động ≤ 1 giây
- Khi giá trị nhiệt độ hoặc độ ẩm vượt ngưỡng, buzzer phải được kích hoạt trong vòng 1 giây.
- Báo động duy trì cho đến khi thông số trở về ngưỡng an toàn hoặc người dùng tắt thủ công bằng nút Reset.
4. Yêu cầu hệ thống (System Requirements)
4.1.Phần cứng (Hardware)
- Vi điều khiển: ATmega 328 hoặc tương tự, có khả năng giao tiếp UART/SPI/I2C.
- Cảm biến nhiệt độ và độ ẩm: AHT20((I²C).
- LCD 16x2.
- Kết nối Wi-Fi: Module ESP8266 để truyền dữ liệu lên Internet.
- Nguồn cấp: 5V DC qua adapter.
- Báo động: Buzzer.
- Nút nhấn Reset/Stop alarm
- Bộ nhớ: EEPROM/Flash để lưu trữ tạm dữ liệu khi mất kết nối mạng.
- Nguồn 12V-1A, IC ổn áp xuống 5V và 3.3V

4.2.Phần mềm nhúng (Embedded Software)
- Xử lý dữ liệu: nhiệt độ, độ ẩm.
- Điều khiển LCD hiển thị.
- Gửi dữ liệu qua Wi-Fi.
- So sánh với ngưỡng → bật/tắt buzzer/LED.
- Lưu dữ liệu khi mất Wi-Fi, đồng bộ khi phục hồi. 4.3.Kết nối IoT (IoT Connectivity)
- Wi-Fi: Chuẩn 2.4 GHz, cấu hình qua AT command.
- ThingSpeak: Field1 = Temp, Field2 = Humi.
- HTTP POST hoặc MQTT.
- Gắn timestamp bằng NTP hoặc RTC.
4.4.Giao diện người dùng (User Interface)
- Trên LCD: Temp & Humi.
- ThingSpeak: Line chart (Temp & Humi).
- Báo động tại chỗ (Buzzer).

Web/Ứng dụng IoT:

- Hiển thị dữ liệu nhiệt độ và độ ẩm theo thời gian thực.
- Biểu đồ dữ liệu theo ngày/giờ.
- Cảnh báo khi nhiệt độ hoặc vượt ngưỡng (qua email/app).
- Nút nhấn (nếu có): Reset kết nối Wi-Fi hoặc cấu hình lại thiết bị. 4.5.Hiệu năng (Performance)
- Độ chính xác nhiệt độ: ±0.3°C
- Độ chính xác độ ẩm: ±0.2% RH
- Tần suất đo và gửi: 1 lần/10s (cấu hình được).
- Độ trễ dữ liệu: < 2s (trong điều kiện Wi-Fi ổn định).
- Độ tin cậy: Hệ thống phải tự động kết nối lại khi mất Wi-Fi.
5. Ràng buộc (Constraints)
- Chỉ hoạt động trong vùng có Wi-Fi.
- Giới hạn bởi khả năng xử lý của vi điều khiển ATmega 328.
- Lưu trữ cục bộ chỉ mang tính tạm thời.
6. Khả năng mở rộng (Future Expansion)
- Hỗ trợ nhiều cảm biến (nhiệt độ, độ ẩm, ánh sáng).
- Tích hợp Bluetooth cho cấu hình ban đầu.
- Hỗ trợ pin và năng lượng mặt trời cho ứng dụng di động.
7. Use case modelling
7.1. Log Temperature & Humidity Data to ThingSpeak

Use Case Name | Log Temperature & Humidity Data to ThingSpeak
Use Case ID | UC001
Scope | System based on ATmega328 microcontroller (MCU), AHT20 sensor (I²C), Wi-Fi module (ESP8266), and ThingSpeak API for IoT data storage and visualization.
Primary Actor(s) | • ATmega328 MCU • AHT20 Sensor (Temperature + Humidity) • Wi-Fi Module (ESP8266) • ThingSpeak Cloud
Stakeholders and Interests | • User: Muốn giám sát nhiệt độ và độ ẩm từ xa thông qua ThingSpeak. • System: Đọc dữ liệu từ AHT20, xử lý và gửi đúng định dạng API. • ThingSpeak Server: Nhận dữ liệu hợp lệ để lưu và hiển thị trên kênh.
Preconditions | • ATmega328 được cấp nguồn và khởi tạo. • Module Wi-Fi kết nối thành công với mạng Wi-Fi. • Tài khoản ThingSpeak có API Key hợp lệ. • AHT20 được kết nối I²C (SDA, SCL).
Postconditions | • Dữ liệu nhiệt độ (°C) và độ ẩm (%) lưu trên ThingSpeak channel. • Người dùng có thể giám sát dữ liệu qua web.
Main Flow of Events | • ATmega328 khởi tạo giao tiếp I²C và UART. • ATmega328 gửi lệnh khởi tạo AHT20 (0xBE, 0x08, 0x00). • ATmega328 gửi lệnh trigger đo (0xAC, 0x33, 0x00). • Chờ 75ms, sau đó đọc 6 byte dữ liệu từ AHT20. • Tính toán độ ẩm và nhiệt độ. • ATmega328 gửi dữ liệu qua UART đến ESP8266. • ThingSpeak server lưu dữ liệu vào channel. • Người dùng truy cập để xem biểu đồ nhiệt độ và độ ẩm.
Alternative Flow – Wi-Fi Error | • Nếu không kết nối được Wi-Fi → thử lại sau 5s. • Nếu vẫn lỗi → báo bằng LED nhấp nháy.
Alternative Flow – Sensor Error | • Nếu AHT20 không phản hồi → gửi giá trị mặc định (-1, -1). • Vẫn update ThingSpeak để biết trạng thái lỗi.
Exception Flows | • Mất nguồn → hệ thống khởi động lại và tiếp tục đo. • ThingSpeak từ chối dữ liệu → MCU ghi nhận lỗi và thử lại sau 20s.
Includes | • UC002: Read Temp & Humidity from AHT20 (I²C) • UC003: Connect to Wi-Fi (ESP8266)
Extends | • UC004: Visualize Temp & Humidity on ThingSpeak
Special Requirements | • Chu kỳ gửi dữ liệu ≥ 15 giây (giới hạn ThingSpeak free).

- Điện áp AHT20: 2.0–5.5V (tương thích ATmega328).
- I²C tốc độ chuẩn (100kHz hoặc 400kHz).
7.2. Read Temp & Humidity from AHT20 (I²C)
Use Case Name | Read Temp & Humidity from AHT20
Use Case ID | UC002
Scope | ATmega328 communicates with AHT20 sensor via I²C to obtain temperature and humidity data.
Primary Actor(s) | • ATmega328 MCU • AHT20 Sensor
Stakeholders and Interests | • MCU: Cần đọc dữ liệu nhiệt độ và độ ẩm chính xác từ sensor • System: Đảm bảo giao tiếp I²C ổn định và xử lý lỗi phù hợp • User: Nhận được dữ liệu môi trường đáng tin cậy
Preconditions | • AHT20 kết nối SDA, SCL với ATmega328. • ATmega328 đã khởi tạo giao tiếp I²C.
Postconditions | • MCU nhận được dữ liệu nhiệt độ (°C) và độ ẩm (%RH).
Main Flow of Events | • MCU gửi lệnh Initialization (0xBE, 0x08, 0x00) đến AHT20. • MCU gửi lệnh Trigger measurement (0xAC, 0x33, 0x00). • MCU chờ 75ms để AHT20 hoàn thành đo. • MCU đọc 6 byte dữ liệu từ AHT20 qua I²C. MCU tính toán kết quả
Alternative Flow – Sensor Busy | • Nếu bit trạng thái [7] = 1 (sensor đang đo) → chờ thêm 10ms và đọc lại.
Exception Flows | • Nếu không nhận được ACK từ AHT20 → báo lỗi “Sensor not responding”.
7.3. Connect to Wi-Fi (ESP8266)
Use Case Name | Connect to Wi-Fi via ESP8266
Use Case ID | UC003
Scope | ATmega328 communicates with ESP8266 module over UART using AT commands to establish Wi-Fi connection.
Primary Actor(s) | • ATmega328 MCU • ESP8266 Wi-Fi Module
Stakeholders and Interests | • MCU: Cần kết nối Wi-Fi ổn định để truyền dữ liệu • System: Đảm bảo kết nối mạng đáng tin cậy • User: Muốn có kết nối internet liên tục để giám sát từ xa
Preconditions | • ESP8266 được cấp nguồn 3.3V ổn định. • ATmega328 UART đã khởi tạo (baud rate phù hợp, ví dụ 9600/115200).

Postconditions | • ESP8266 kết nối thành công đến Access Point (Wi-Fi).
Main Flow of Events | • MCU gửi lệnh kiểm tra: AT → ESP8266 trả về OK. • MCU gửi lệnh đặt chế độ Wi-Fi Station. • MCU gửi lệnh kết nối Access Point. • ESP8266 trả về WIFI CONNECTED và OK. • MCU kiểm tra IP. • ESP8266 trả về địa chỉ IP.
Alternative Flow – Wrong Password | • Nếu ESP8266 trả về FAIL → MCU thử lại tối đa 3 lần, sau đó báo lỗi. Exception Flows • Nếu ESP8266 không phản hồi → kiểm tra nguồn và UART.

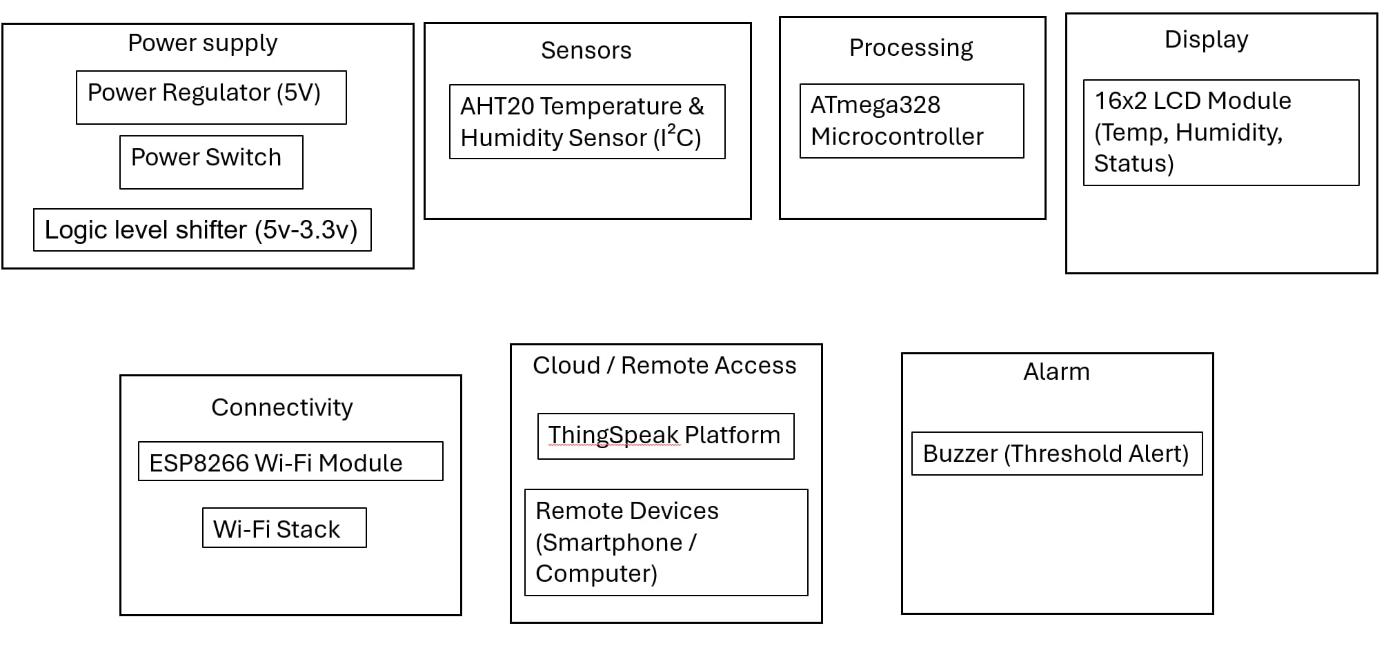
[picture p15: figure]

8. System architecture

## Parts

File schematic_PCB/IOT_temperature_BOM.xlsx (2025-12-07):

Line | Name | Description | Designator | Quantity | Manufacturer 1 | Manufacturer Part Number 1 | Manufacturer Lifecycle 1 | Supplier 1 | Supplier Part Number 1 | Supplier Unit Price 1 | Supplier Subtotal 1
1 | 22µF/16V |  | C1, C7 | 2
2 | 0.1uF | Cap np 104 => 105pF | C2, C8, C9, C10, C11, C12, C15, C16, C17, C18, C19, C20, C21 | 13
3 | 10µF/16V |  | C3, C6 | 2
4 | 47µF/35V |  | C4, C5 | 2
5 | 22pF | Cap np W0.3 | C13, C14 | 2
6 | GREEN | Green 569nm LED Indication - Discrete 2.1V 0603 (1608 Metric) | D1, D2, D4 | 3
7 | Diode | Default Diode | D3 | 1
8 | L7805 |  | IC1 | 1
9 | 12V/1A | 2 Position Wire to Board Terminal Block Horizontal with Board 0.200" (5.08mm) Through Hole | J1 | 1
10 | JP6 | WR-PHD 2.54 mm Angled Socket Header | J2 | 1
11 | HD 5x2 |  | P1 | 1
12 | 2N3904 | NPN 600mW, ECB | Q1 | 1
13 | 1k |  | R1, R2 | 2
14 | 10k |  | R3, R6, R10 | 3
15 | 1K |  | R4 | 1
16 | 220 omh |  | R5 | 1
17 | 4.7k |  | R7, R8 | 2
18 | 1M |  | R9 | 1
19 | 680 omh |  | R11 | 1
20 | RESET MCU | Switch-Button | S1 | 1
21 | RESET_WIFI | Switch-Button | S2 | 1
22 | ALARM MUTE | Switch-Button | S3 | 1
23 | LM1117-3.3V | Low-Dropout Linear Regulator | U1 | 1
24 | ATmega328-PU | 8-bit AVR Microcontroller, 32KB Flash, 1KB EEPROM, 2KB SRAM, 28-pin PDIP, Industrial Grade (-40°C to 85°C) | U2 | 1 | Microchip | ATMEGA328-PU | Volume Production | DigiKey | ATMEGA328-PU-ND | 2.63 | 2.63
25 | AHT20 |  | U3 | 1
26 | ESP8266 ESP-01 | ESP8266 ESP-01 | U4 | 1
27 | LOGIC LEVEL SHIFTER |  | U5 | 1
28 | buzzer |  | U6 | 1
29 | LCD |  | U7 | 1
30 | 10K | Var Resistor | VR1 | 1
31 | 16MHz |  | X1 | 1

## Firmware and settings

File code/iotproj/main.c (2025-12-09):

#include "BOARD.h" // B?T BU?C: Ph?i ? ??u tiên ?? l?y F_CPU

#include <avr/io.h>
#include <avr/interrupt.h>
#include <util/delay.h>
#include <stdlib.h>
#include <stdio.h>

// Include các th? vi?n driver
#include "LCD.h"      // Gi? s? b?n ?ã có file này
#include "ESP8266.h"  // ?ã bao g?m UART bên trong
#include "AHT20.h"    // ?ã bao g?m TWI bên trong

// ==========================
// C?u hình Chân & Ng??ng
// ==========================
#define LED_PIN         PC3 // LED báo tr?ng thái/Alarm
#define BUTTON_PIN      PD2 // Nút nh?n (INT0)
#define BUZZER_PIN      PD3 // Còi báo ??ng

#define TEMP_THRESHOLD  30.0f
#define HUM_THRESHOLD   60.0f

#define UPLOAD_INTERVAL 15  // Chu k? upload (giây)

// ==========================
// Bi?n toàn c?c
// ==========================
volatile uint8_t button_pressed = 0;
volatile uint8_t alarm_enabled = 1; // 1: B?t c?nh báo, 0: T?t
char display_buffer[20];

// ==========================
// Interrupt Service Routine (INT0)
// ==========================
ISR(INT0_vect) {
	// Ch? b?t s? ki?n, x? lý s? làm ? main loop ?? tránh delay trong ISR
	if (!(PIND & (1 << BUTTON_PIN))) {
		button_pressed = 1;
	}
}

// ==========================
// Hàm h? tr? ph?n c?ng
// ==========================
void Hardware_Init(void) {
	// 1. C?u hình Buzzer (PD3) & LED (PC3) là Output
	DDRD |= (1 << BUZZER_PIN);
	DDRC |= (1 << LED_PIN);
	
	// Tr?ng thái ban ??u
	PORTD &= ~(1 << BUZZER_PIN); // T?t Buzzer
	if (alarm_enabled) PORTC |= (1 << LED_PIN); // B?t LED n?u alarm ?ang enable
	
	// 2. C?u hình Button (PD2) là Input Pull-up
	DDRD &= ~(1 << BUTTON_PIN);
	PORTD |= (1 << BUTTON_PIN);
	
	// 3. C?u hình ng?t ngoài INT0 (C?nh xu?ng)
	EICRA |= (1 << ISC01);
	EICRA &= ~(1 << ISC00);
	EIMSK |= (1 << INT0);
	
	sei(); // Cho phép ng?t toàn c?c
}

void Check_Button_Process(void) {
	if (button_pressed) {
		_delay_ms(50); // Debounce
		
		if (!(PIND & (1 << BUTTON_PIN))) { // Ki?m tra ch?c ch?n còn nh?n
			// ??o tr?ng thái c?nh báo
			alarm_enabled = !alarm_enabled;
			
			// C?p nh?t LED và Buzzer ngay l?p t?c
			if (alarm_enabled) {
				PORTC |= (1 << LED_PIN); // LED ON báo hi?u h? th?ng Alarm b?t
				} else {
				PORTC &= ~(1 << LED_PIN);  // LED OFF
				PORTD &= ~(1 << BUZZER_PIN); // T?t Buzzer ngay n?u ?ang kêu
			}
			
			// Ch? nh? nút
			while (!(PIND & (1 << BUTTON_PIN)));
		}
		button_pressed = 0; // Xóa c?
		
		// Xóa c? ng?t ?? tránh kích ho?t l?i ngay l?p t?c (INTF0)
		EIFR |= (1 << INTF0);
	}
}

void Alarm_Logic(float temp, float hum) {
	if (alarm_enabled) {
		if (temp > TEMP_THRESHOLD || hum > HUM_THRESHOLD) {
			PORTD |= (1 << BUZZER_PIN); // B?t còi
			} else {
			PORTD &= ~(1 << BUZZER_PIN); // T?t còi
		}
		} else {
		PORTD &= ~(1 << BUZZER_PIN); // Luôn t?t còi khi alarm disabled
	}
}

// Hàm delay thông minh: V?a delay v?a check nút nh?n
void Delay_With_Button_Check(uint16_t ms) {
	uint16_t loops = ms / 10;
	for (uint16_t i = 0; i < loops; i++) {
		_delay_ms(10);
		Check_Button_Process();
	}
}

// ==========================
// Hàm Main
// ==========================
int main(void) {
	float temp = 0.0, hum = 0.0;
	uint8_t wifi_status = 0;
	uint8_t time_count = 0;

	// 1. Kh?i t?o
	Hardware_Init();
	LCD_Init();
	
	LCD_SetCursor(0, 0);
	LCD_PrintString("System Init...");
	
	AHT20_Init(); // T? ??ng g?i I2C_Init
	ESP8266_Init(); // T? ??ng g?i UART_Init
	
	// 2. K?t n?i WiFi ban ??u
	LCD_SetCursor(0, 0);
	LCD_PrintString("Connecting WiFi ");
	wifi_status = ESP8266_ConnectWiFi();
	
	if(wifi_status) {
		LCD_SetCursor(1, 0);
		LCD_PrintString("WiFi: OK        ");
		} else {
		LCD_SetCursor(1, 0);
		LCD_PrintString("WiFi: Failed    ");
	}
	_delay_ms(1000);
	LCD_Clear();

	// ==========================
	// Vòng l?p chính
	// ==========================
	while (1) {
		// A. ??c c?m bi?n
		AHT20_ReadAll(&temp, &hum);
		
		// B. X? lý hi?n th? LCD
		LCD_SetCursor(0, 0);
		sprintf(display_buffer, "T:%.1fC H:%.1f%%", temp, hum);
		LCD_PrintString(display_buffer);
		
		// C. X? lý C?nh báo (Alarm)
		Alarm_Logic(temp, hum);
		
		// Hi?n th? tr?ng thái Alarm trên LCD dòng 2
		LCD_SetCursor(1, 0);
		if (alarm_enabled) LCD_PrintString("ALM:ON ");
		else               LCD_PrintString("ALM:OFF");
		
		// D. X? lý Upload ThingSpeak (m?i UPLOAD_INTERVAL giây)
		if (++time_count >= UPLOAD_INTERVAL) {
			time_count = 0;
			LCD_SetCursor(1, 8);
			LCD_PrintString(" Upld...");
			
			// Th? g?i d? li?u
			if (ESP8266_SendToThingSpeak(temp, hum)) {
				LCD_SetCursor(1, 8);
				LCD_PrintString(" S-OK   ");
				} else {
				LCD_SetCursor(1, 8);
				LCD_PrintString(" S-ERR  ");
				// N?u l?i, th? k?t n?i l?i WiFi cho l?n sau
				ESP8266_ConnectWiFi();
			}
			Delay_With_Button_Check(1000); // Show tr?ng thái g?i trong 1s
			} else {
			// Hi?n th? ??m ng??c (Optional)
			LCD_SetCursor(1, 8);
			sprintf(display_buffer, " Next:%2d", UPLOAD_INTERVAL - time_count);
			LCD_PrintString(display_buffer);
		}

		// E. Delay chu k? (1 giây)
		// Thay vì _delay_ms(1000) c?ng, ta dùng hàm check nút
		Delay_With_Button_Check(1000);
	}
	
	return 0;
}

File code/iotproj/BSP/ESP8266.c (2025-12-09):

#include "ESP8266.h"

//=====================//
//   ESP8266 Functions //
//=====================//

void ESP8266_SendCommand(const char *cmd) {
	UART_Flush(); // Dùng hàm t? driver UART.h
	UART_SendString(cmd);
	UART_SendString("\r\n");
}

uint8_t ESP8266_WaitResponse(const char *expected, uint16_t timeout_ms) {
	static char response[384];
	uint16_t index = 0;
	uint32_t start_time = 0;
	uint32_t timeout_loops = (uint32_t)timeout_ms * 100; // 1 loop ~ 10us
	
	memset(response, 0, sizeof(response));
	
	while (start_time < timeout_loops) {
		if (UART_Available()) {
			// Thay th? UDR0 b?ng hàm nh?n t? driver
			char c = UART_ReceiveChar();
			
			if (index < sizeof(response) - 1) {
				response[index++] = c;
				response[index] = '\0';
				} else {
				// Shift buffer n?u ??y
				memmove(response, response + 1, sizeof(response) - 2);
				index = sizeof(response) - 2;
				response[index++] = c;
				response[index] = '\0';
			}
			
			if (strstr(response, expected) != NULL) {
				return 1;
			}
			} else {
			_delay_us(10);
			start_time++;
		}
	}
	return 0; // Timeout
}

uint8_t ESP8266_WaitMultiResponse(const char *resp1, const char *resp2, uint16_t timeout_ms) {
	static char response[384];
	uint16_t index = 0;
	uint32_t start_time = 0;
	uint32_t timeout_loops = (uint32_t)timeout_ms * 100;
	
	memset(response, 0, sizeof(response));
	
	while (start_time < timeout_loops) {
		if (UART_Available()) {
			// Thay th? UDR0 b?ng hàm nh?n t? driver
			char c = UART_ReceiveChar();
			
			if (index < sizeof(response) - 1) {
				response[index++] = c;
				response[index] = '\0';
				} else {
				memmove(response, response + 1, sizeof(response) - 2);
				index = sizeof(response) - 2;
				response[index++] = c;
				response[index] = '\0';
			}
			
			if (strstr(response, resp1) != NULL || strstr(response, resp2) != NULL) {
				return 1;
			}
			} else {
			_delay_us(10);
			start_time++;
		}
	}
	return 0;
}

void ESP8266_ReadResponse(char *buffer, uint16_t max_len, uint16_t timeout_ms) {
	uint16_t index = 0;
	uint32_t start_time = 0;
	uint32_t timeout_loops = (uint32_t)timeout_ms * 100;
	
	memset(buffer, 0, max_len);
	
	while (start_time < timeout_loops && index < max_len - 1) {
		if (UART_Available()) {
			buffer[index++] = UART_ReceiveChar();
			buffer[index] = '\0';
			} else {
			_delay_us(10);
			start_time++;
		}
	}
}

void ESP8266_Init(void) {
	UART_Init(); // G?i hàm kh?i t?o t? driver
	_delay_ms(1000);
	
	// Reset ESP8266 ?? ??m b?o tr?ng thái s?ch
	ESP8266_SendCommand("AT+RST");
	_delay_ms(2500); // Ch? kh?i ??ng l?i
	UART_Flush();
	
	ESP8266_SendCommand("ATE0"); // T?t Echo
	ESP8266_WaitResponse("OK", 1000);
	
	ESP8266_SendCommand("AT+CWMODE=1"); // Station Mode
	ESP8266_WaitResponse("OK", 2000);
	
	ESP8266_SendCommand("AT+CIPMUX=0"); // Single Connection (QUAN TR?NG)
	ESP8266_WaitResponse("OK", 1000);
}

uint8_t ESP8266_ConnectWiFi(void) {
	char cmd[100];
	
	// Ng?t k?t n?i c?
	ESP8266_SendCommand("AT+CWQAP");
	ESP8266_WaitResponse("OK", 1000);
	
	_delay_ms(500);
	
	// K?t n?i m?i
	sprintf(cmd, "AT+CWJAP=\"%s\",\"%s\"", WIFI_SSID, WIFI_PASS);
	ESP8266_SendCommand(cmd);
	
	// Ch? k?t n?i (Timeout 15s)
	if (ESP8266_WaitMultiResponse("OK", "WIFI GOT IP", 15000)) {
		_delay_ms(1000);
		return 1;
	}
	return 0;
}

void ESP8266_CloseTCP(void) {
	ESP8266_SendCommand("AT+CIPCLOSE");
	_delay_ms(200);
	UART_Flush();
}

uint8_t ESP8266_SendToThingSpeak(float field1, float field2) {
	char packet_buffer[300];
	char payload[50];
	char cmd_buffer[30];
	
	// 1. D?n d?p k?t n?i c?
	ESP8266_CloseTCP();
	
	// 2. T?o k?t n?i TCP
	ESP8266_SendCommand("AT+CIPSTART=\"TCP\",\"api.thingspeak.com\",80");
	
	if (!ESP8266_WaitMultiResponse("CONNECT", "OK", 10000)) {
		return 0; // Th?t b?i
	}
	
	_delay_ms(200);
	
	// 3. Chu?n b? d? li?u (Payload)
	// X? lý s? float th? công ?? tránh l?i %f trên m?t s? trình biên d?ch AVR c?
	int f1_int = (int)field1;
	int f1_dec = (int)((field1 - f1_int) * 100 + 0.5); if (f1_dec < 0) f1_dec = -f1_dec;
	
	int f2_int = (int)field2;
	int f2_dec = (int)((field2 - f2_int) * 100 + 0.5); if (f2_dec < 0) f2_dec = -f2_dec;
	
	sprintf(payload, "field1=%d.%02d&field2=%d.%02d", f1_int, f1_dec, f2_int, f2_dec);
	
	// 4. T?o gói tin HTTP
	sprintf(packet_buffer,
	"POST /update HTTP/1.1\r\n"
	"Host: api.thingspeak.com\r\n"
	"Connection: close\r\n"
	"X-THINGSPEAKAPIKEY: %s\r\n"
	"Content-Type: application/x-www-form-urlencoded\r\n"
	"Content-Length: %d\r\n\r\n"
	"%s",
	THINGSPEAK_API_KEY, (int)strlen(payload), payload);
	
	// 5. G?i l?nh CIPSEND
	int packet_len = strlen(packet_buffer);
	sprintf(cmd_buffer, "AT+CIPSEND=%d", packet_len);
	ESP8266_SendCommand(cmd_buffer);
	
	// 6. Ch? d?u nh?c '>'
	if (!ESP8266_WaitResponse(">", 5000)) {
		ESP8266_CloseTCP();
		return 0;
	}
	
	// 7. G?i n?i dung
	UART_SendString(packet_buffer);
	
	// 8. Ch? xác nh?n SEND OK
	if (!ESP8266_WaitResponse("SEND OK", 10000)) {
		ESP8266_CloseTCP();
		return 0;
	}
	
	// 9. Ch? ?óng k?t n?i
	ESP8266_WaitResponse("CLOSED", 5000);
	
	return 1; // Thành công
}

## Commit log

2025-10-29 Create Schematic_PCB
2025-12-07 Create Mô Phỏng
